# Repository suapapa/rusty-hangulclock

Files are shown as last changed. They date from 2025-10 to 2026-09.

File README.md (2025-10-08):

# Rusty HangulClock

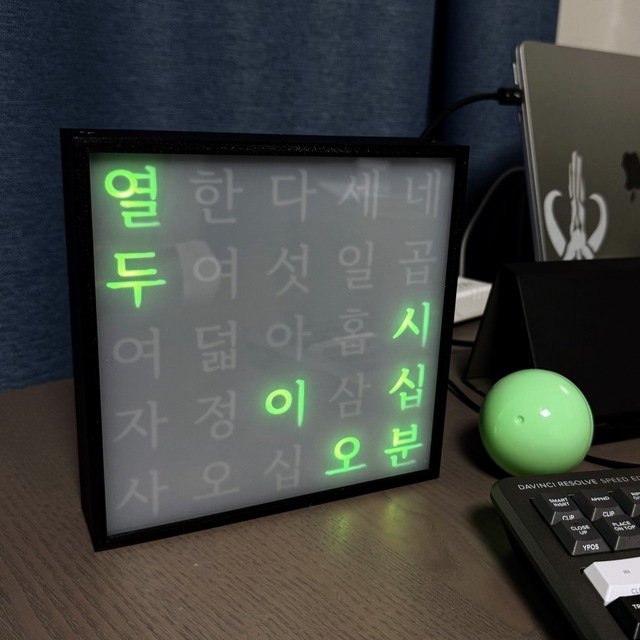
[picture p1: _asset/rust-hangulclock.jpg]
rusty_hangulclock


A HangulClock written in Rust for the ESP32-C3 board.

- [Usage manual](https://hangulclock.homin.dev)
- [Pannel image mager - Web](https://hangulclock.homin.dev/panel-maker)

## Hardware

- [Schematic & PCB artwork](./sch/rusty-hangulclock/) - KiCad project files
- [3D case models](./case/)

## Build and Flash

### Install Toolchain (One-time setup)

```sh
cargo install espup cargo-espflash ldproxy
espup install
```

### Build and Flash

```sh
make flash
```

### Factory Reset

Reset all settings to defaults:

```sh
make erase_nvs
```

## Pre-commit Workflow

Before committing code, run:

```sh
make pre-commit
```

This will run all static analysis tools and ensure your code meets quality standards.

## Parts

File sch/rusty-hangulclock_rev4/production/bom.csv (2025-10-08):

Designator | Footprint | Quantity | Value | LCSC Part #
C1, C10, C11, C12, C13, C14, C15, C17, C18, C19, C2, C20, C21, C22, C23, C24, C25, C26, C27, C28, C3, C30, C31, C34, C4, C6, C7, C8, C9 | C_0402 | 29 | 100nF | C1525
C16, C32, C5 | C_0805 | 3 | 10uF | C15850
C29 | C_0402 | 1 | 22pF | C1555
C35 | C_0402 | 1 | 1uF | C52923
D1 | 0603 | 1 | Red | C2286
D10, D11, D12, D13, D14, D15, D16, D17, D18, D19, D2, D20, D21, D22, D23, D24, D25, D26, D3, D4, D5, D6, D7, D8, D9 | LED_WS2812B_PLCC4_5.0x5.0mm_P3.2mm | 25 | WS2812B | C2874885
D28 | SOT23-6L | 1 | USBLC6-2SC6 | C7519
FB1 | FB_0805 | 1 | ~ | C1015
J4 | USB-TYPE-C-015 | 1 | USB_C_Receptacle_PowerOnly_6P | C2927035
L1 | L_Bourns-SRN4018 | 1 | SPH4018H2R2MT (2.2uH 2.2A) | C370436
Q1, Q2 | Q_SOT-23 | 2 | S8050 | C364312
R1, R5, R8 | R_0402 | 3 | 1kΩ | C11702
R10, R11, R7 | R_0402 | 3 | 10kΩ | C25744
R2, R6 | R_0402 | 2 | 5.1kΩ | C25905
R3 | R_0402 | 1 | 100kΩ | C25741
R4 | R_0402 | 1 | 22kΩ | C25768
U1 | ESP32-C3-WROOM-02 | 1 | ESP32-C3-WROOM-02
U2 | SOT-23-5 | 1 | SY8088 | C479072

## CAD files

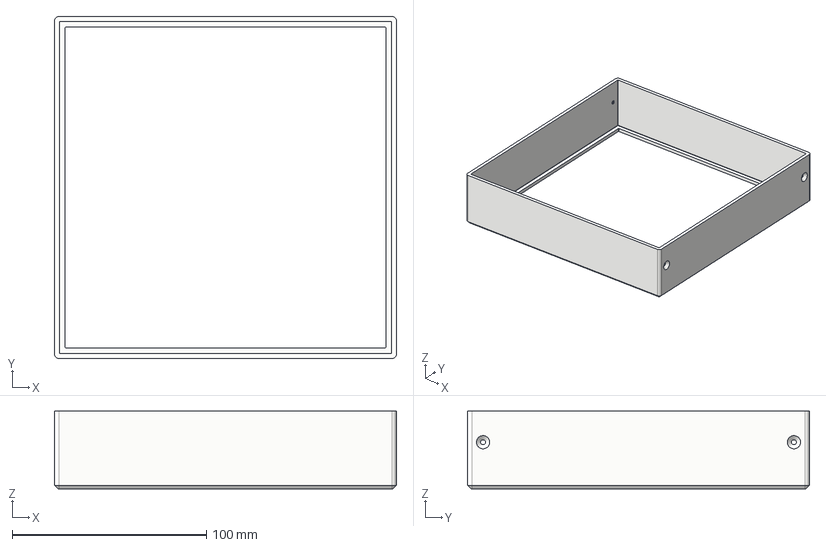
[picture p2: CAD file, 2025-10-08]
case/exp/외부케이스 176x176.step
176.0 x 176.0 x 40.0 mm

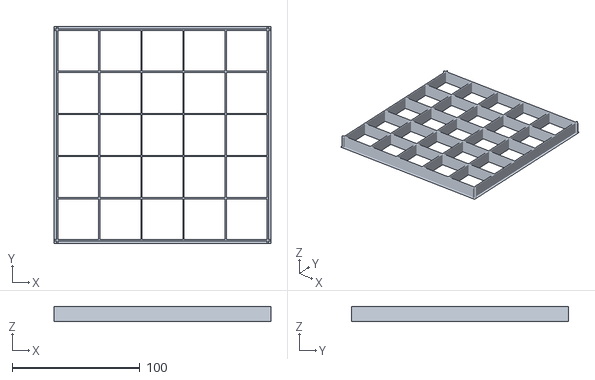
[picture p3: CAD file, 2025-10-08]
case/light_tunnel.stl
170.0 x 170.0 x 12.0

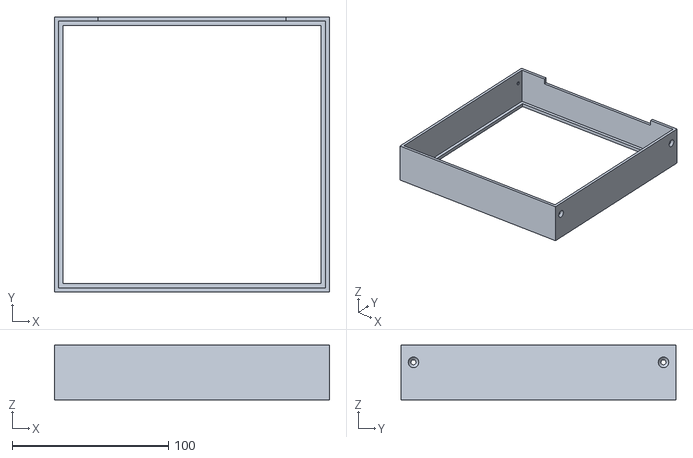
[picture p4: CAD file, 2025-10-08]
case/case.stl
176.0 x 176.0 x 35.0

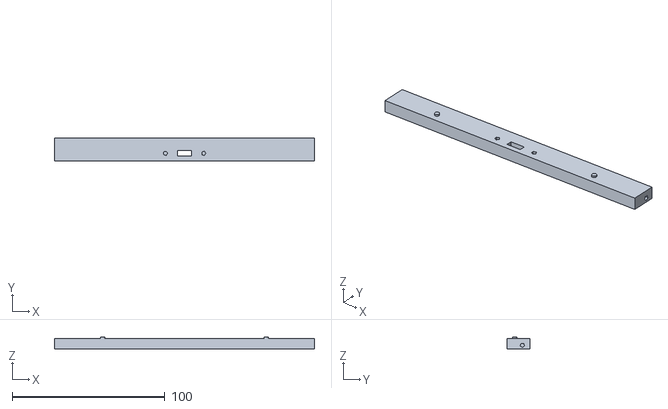
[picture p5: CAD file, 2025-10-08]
case/bridge_bottom.stl
170.0 x 15.0 x 8.00

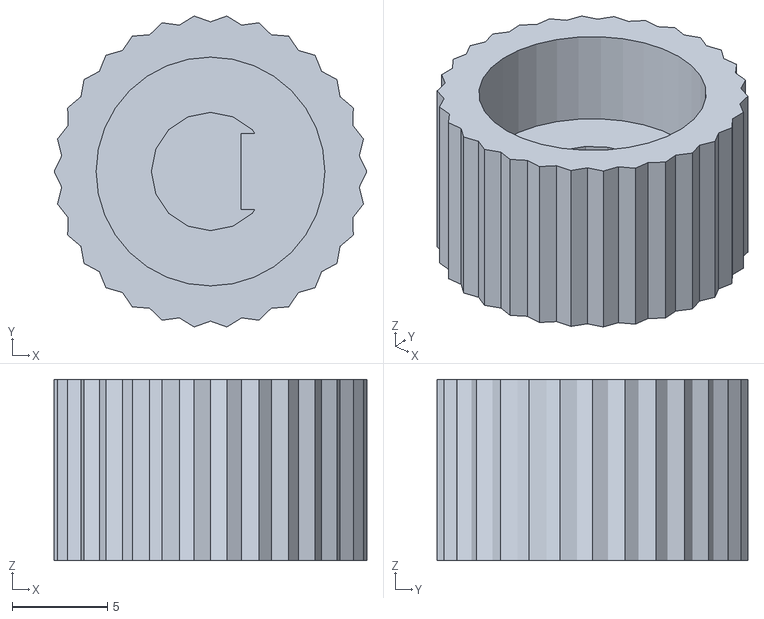
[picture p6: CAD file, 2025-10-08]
case/knob.stl
16.4 x 16.3 x 9.50

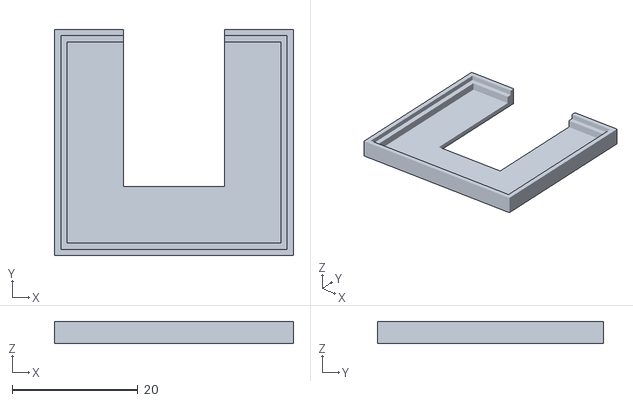
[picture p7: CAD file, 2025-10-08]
case/oled_guide.stl
38.0 x 36.0 x 3.50

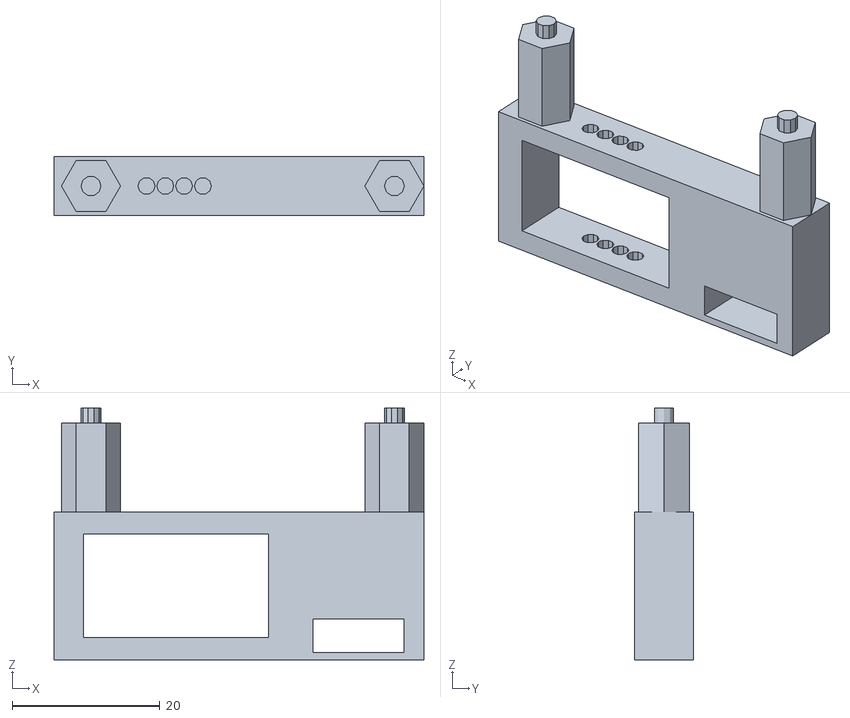
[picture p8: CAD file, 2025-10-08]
case/download_zig.stl
50.0 x 8.00 x 34.0

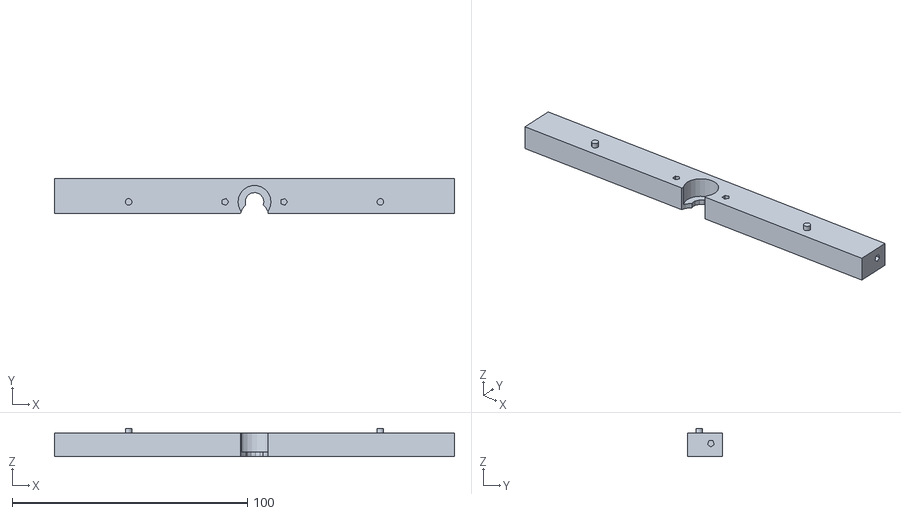
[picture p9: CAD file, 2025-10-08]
case/bridge_top.stl
170.0 x 15.0 x 12.0

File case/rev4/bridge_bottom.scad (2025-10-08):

bar();

module bar(){
    translate([0,0,0])
union(){
    difference() {
        translate([0,2.5,1.5]) cube ([170, 15, 7], center=true);
        #translate([12.5, 0, 4]) cylinder(10, 1.5, 1.5, center=true);
        #translate([-12.5, 0, 4]) cylinder(10, 1.5, 1.5, center=true);
        
        // usb hole
        # cube([9,3.5,10+1], center=true);
        
        // sideholes
        translate([170/2,5,0.6]) rotate([0,90,0]) cylinder(20, 1.5, 1.5, center=true);
        translate([-170/2,5,0.6]) rotate([0,90,0]) cylinder(20, 1.5, 1.5, center=true);
    }
    translate([53.5, 0, 2]) cylinder(8, 1.4, 1.4, center=true, $fn=20);
    translate([-53.5, 0, 2]) cylinder(8, 1.4, 1.4, center=true, $fn=20);
}
}

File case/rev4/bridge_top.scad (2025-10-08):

union(){
    difference() {
        translate([0,2.5,0]) cube ([170, 15 , 10], center=true);
        translate([12.5, 0, 3]) cylinder(10, 1.5, 1.5, center=true);
        translate([-12.5, 0, 3]) cylinder(10, 1.5, 1.5, center=true);
        
        // wall nail hole
        translate([0,0,0]) cylinder(11, 4, 4, center=true);
        translate([0,-6,0]) cylinder(11, 6, 6, center=true);
        translate([0,0,2]) cylinder(10, 7, 7, center=true);
        
        // sideholes
        translate([170/2,5,0.6]) rotate([0,90.0]) cylinder(20, 1.5, 1.5, center=true);
        translate([-170/2,5,0.6]) rotate([0,90.0]) cylinder(20, 1.5, 1.5, center=true);
    }
    translate([53.5, 0, 2]) cylinder(10, 1.4, 1.4, center=true, $fn=20);
    translate([-53.5, 0, 2]) cylinder(10, 1.4, 1.4, center=true, $fn=20);
}

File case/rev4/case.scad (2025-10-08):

difference() {
    translate([0,0,40/2])
        difference() {
            cube([176,176,40-5], center=true);
            cube([165,165,70], center=true);
            translate([0,0,3+2.5]) cube([171,171,40], center=true);
            //translate([2.5,2.5,2.5]) cube([170,170,70]);
            translate([0,50,0+25+5]) cube([120,180,35], center=true);
        }

    translate([-170/2,170/2-5,24+2.5])
        rotate([0,90,0]) screw_hole();
    translate([-170/2,-170/2+5,24+2.5])
        rotate([0,90,0]) screw_hole();
    translate([170/2,170/2-5,24+2.5])
        rotate([0,-90,0]) screw_hole();
    translate([170/2,-170/2+5,24+2.5])
        rotate([0,-90,0]) screw_hole();
}



module screw_hole() {
    translate([0,0,-3])
    union() {
        translate([0,0,5]) cylinder(10, 1.5+0.1, 1.5+0.1, center=true, $fn=20);
        translate([0,0,2.5/2-0.2]) cylinder(2.5+0.1,3.5+0.1,1.5, center=true, $fn=20);
    }
}

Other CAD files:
case/rev4/download_zig.scad
case/exp/외부케이스 176x176.stl
case/rev3/case.scad
case/rev3/case_back.scad
case/rev3/light_pannel.scad
case/rev4/knob.scad
case/rev4/light_tunnel.scad
case/rev4/oled_guide.scad

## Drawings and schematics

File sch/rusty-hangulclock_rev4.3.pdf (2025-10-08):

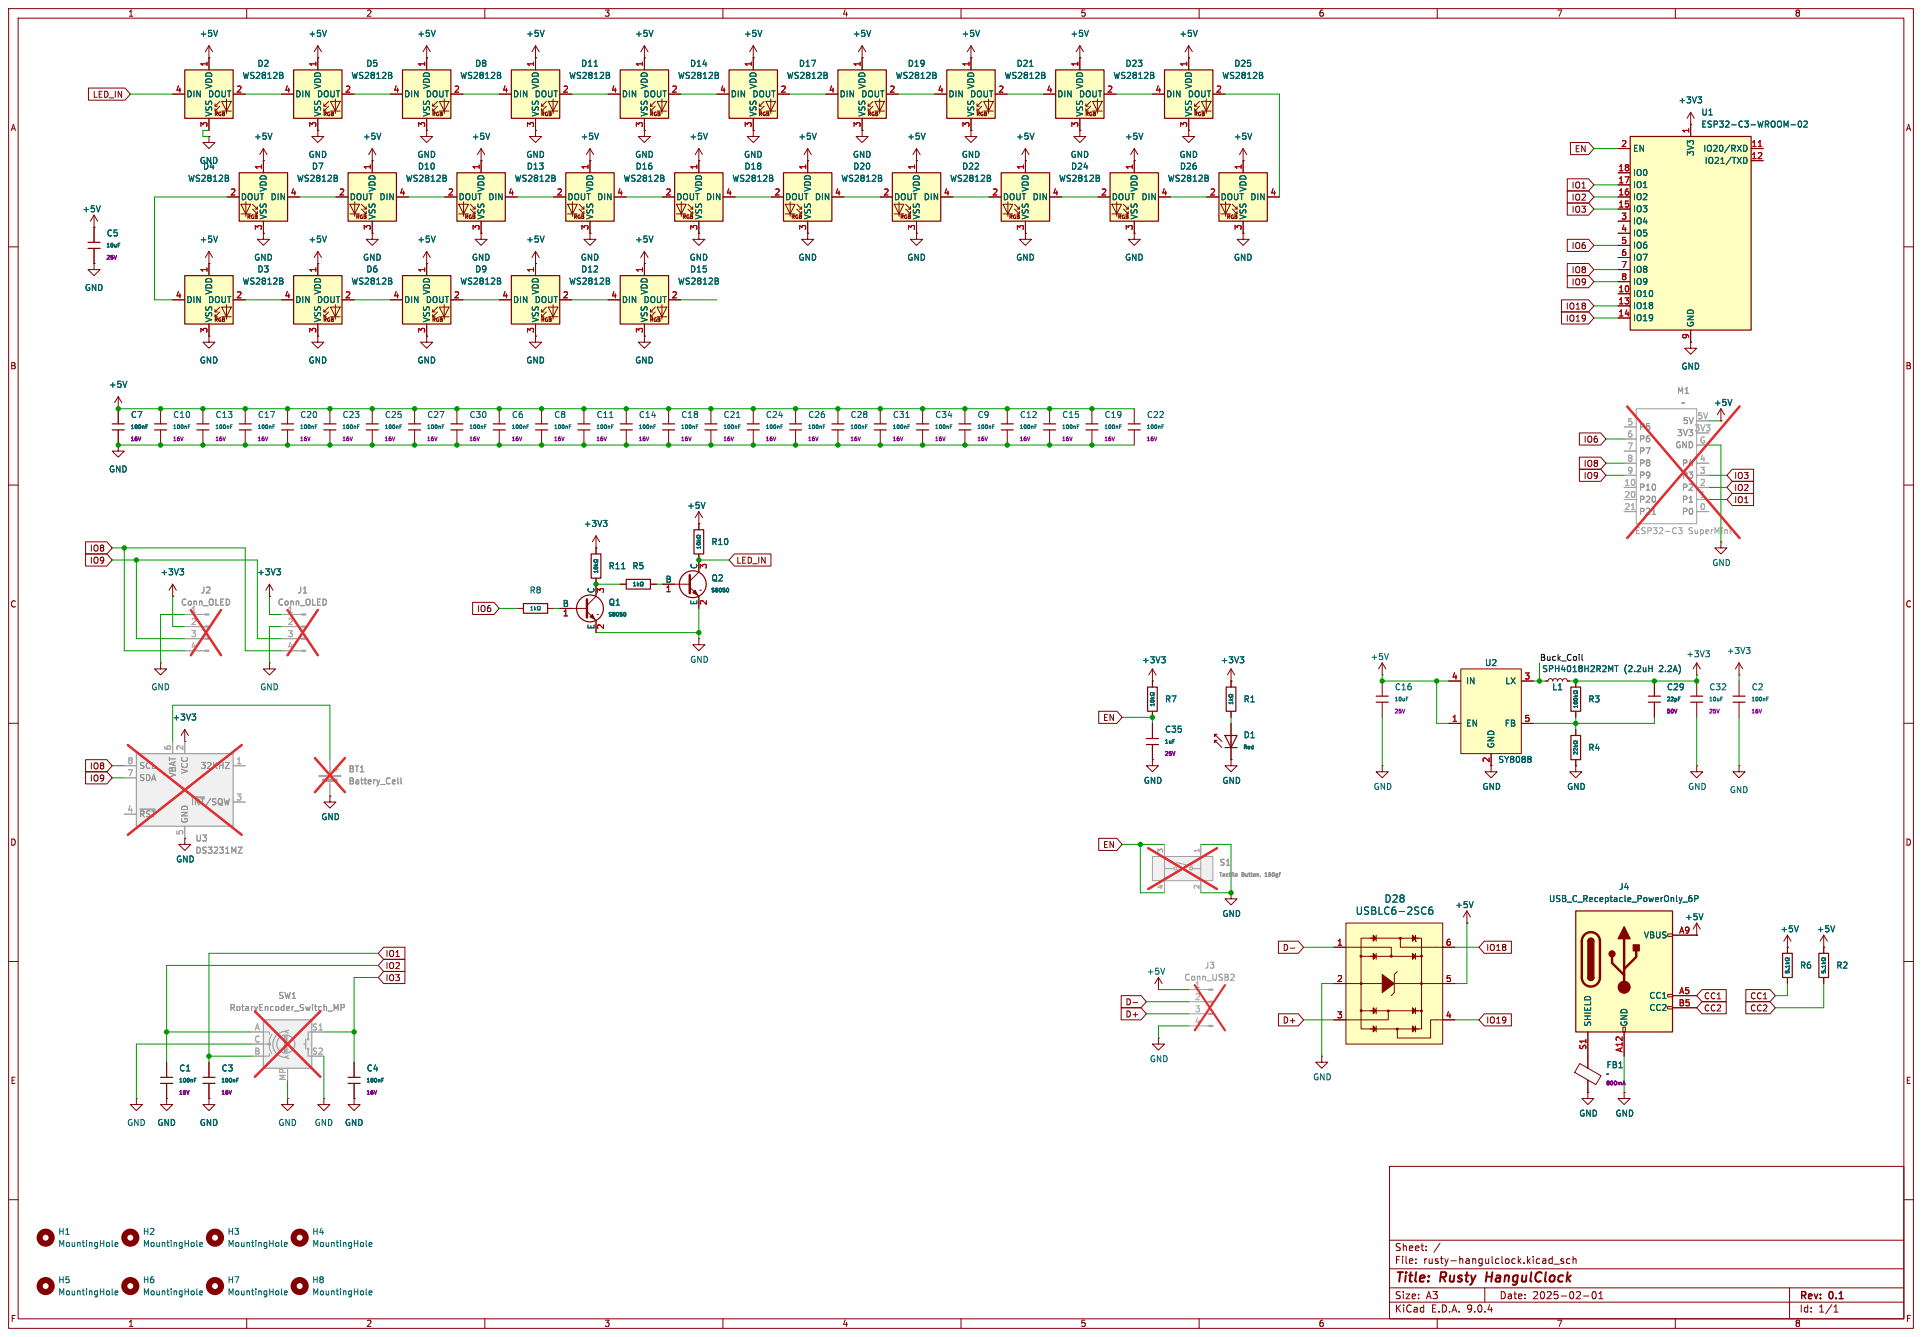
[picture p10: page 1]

3 DOUT 2 D18 WS2812B GND GND GND

File: rusty-hangulclock.kicad_sch Sheet: /
Id: 1/1 Title: Rusty HangulClock

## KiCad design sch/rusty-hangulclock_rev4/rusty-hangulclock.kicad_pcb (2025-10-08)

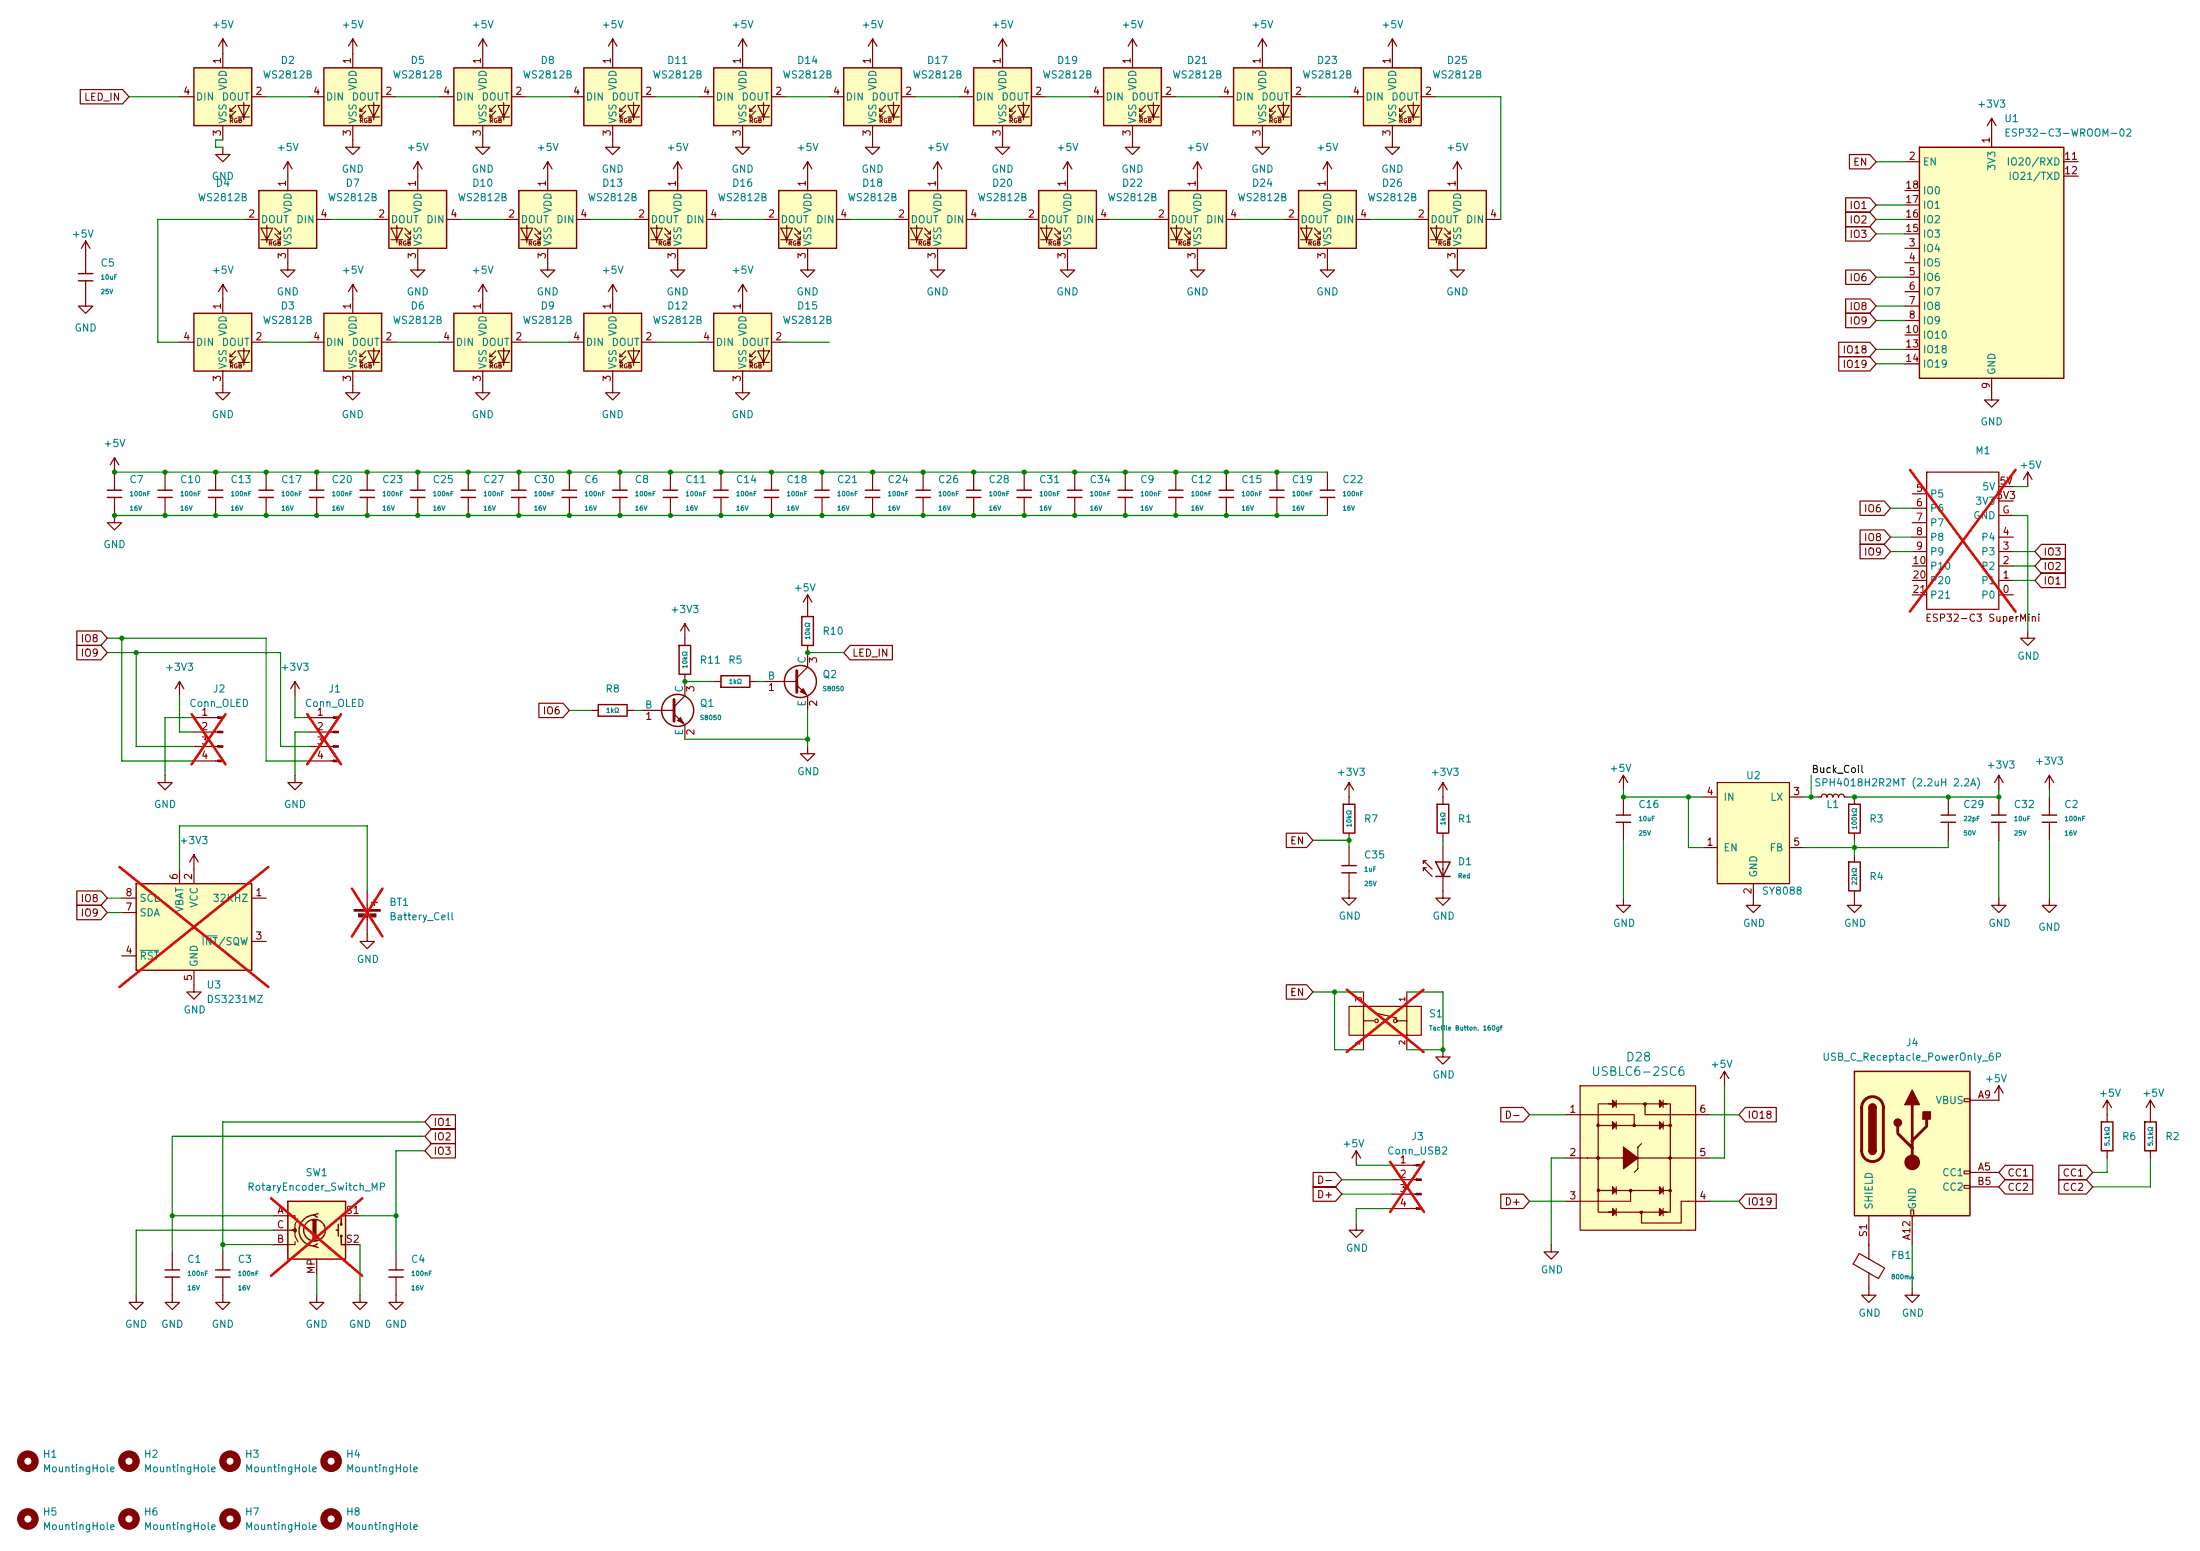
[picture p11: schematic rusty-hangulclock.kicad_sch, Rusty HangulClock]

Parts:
BT1: Battery_Cell; BatteryHolder_Keystone_1060_1x2032; LCSC C70377; not fitted
C1, C2, C3, C4, C6, C7, C8, C9, C10, C11, C12, C13, C14, C15, C17, C18, C19, C20, C21, C22, C23, C24, C25, C26, C27, C28, C30, C31, C34: 100nF; C_0402; Voltage Rated 16V; Tolerance ±10%; Part CL05B104KO5NNNC; LCSC C1525
C5, C16, C32: 10uF; C_0805; Voltage Rated 25V; Tolerance ±10%; Part CL21A106KAYNNNE; LCSC C15850
C29: 22pF; C_0402; Voltage Rated 50V; Tolerance ±5%; Part 0402CG220J500NT; LCSC C1555
C35: 1uF; C_0402; Voltage Rated 25V; Tolerance ±10%; Part CL05A105KA5NQNC; LCSC C52923
D1: Red; LED_0603_1608Metric; Part KT-0603R; LCSC C2286
D2, D3, D4, D5, D6, D7, D8, D9, D10, D11, D12, D13, D14, D15, D16, D17, D18, D19, D20, D21, D22, D23, D24, D25, D26: WS2812B; LED_WS2812B_PLCC4_5.0x5.0mm_P3.2mm; LCSC C2874885
D28: USBLC6-2SC6; SOT23-6L; MPN USBLC6-2SC6; Digi-Key_PN 497-5235-1-ND
FB1: FB_0805; Current Rating 800mA; Tolerance ±25%; Part GZ2012D101TF; LCSC C1015
H1, H2, H3, H4, H5, H6, H7, H8: MountingHole; MountingHole_3.2mm_M3
J1, J2: Conn_OLED; PinHeader_1x04_P2.54mm_Vertical; not fitted
J3: Conn_USB2; PinHeader_1x04_P2.54mm_Vertical; not fitted
J4: USB_C_Receptacle_PowerOnly_6P; USB-TYPE-C-015; LCSC C2927035
L1: SPH4018H2R2MT (2.2uH 2.2A); L_Bourns-SRN4018; LCSC C370436
M1: ESP32-C3_SuperMini_THT; not fitted
Q1, Q2: S8050; Q_SOT-23; Part S8050; LCSC C364312
R1, R5, R8: 1kΩ; R_0402; Overload Voltage (Max) 50V; Tolerance ±1%; Part 0402WGF1001TCE; LCSC C11702
R2, R6: 5.1kΩ; R_0402; Overload Voltage (Max) 50V; Tolerance ±1%; Part 0402WGF5101TCE; LCSC C25905
R3: 100kΩ; R_0402; Overload Voltage (Max) 50V; Tolerance ±1%; Part 0402WGF1003TCE; LCSC C25741
R4: 22kΩ; R_0402; Overload Voltage (Max) 50V; Tolerance ±1%; Part 0402WGF2202TCE; LCSC C25768
R7, R10, R11: 10kΩ; R_0402; Overload Voltage (Max) 50V; Tolerance ±1%; Part 0402WGF1002TCE; LCSC C25744
S1: Tactile Button, 160gf; SW-SMD_4P-L5.1-W5.1-P3.70-LS6.5-TL-2; Voltage Rating (Dc) 12V; Part TS-1187A-B-A-B; LCSC C318884; not fitted
SW1: RotaryEncoder_Switch_MP; RotaryEncoder_Alps_EC11E-Switch_Vertical_H20mm; not fitted
U1: ESP32-C3-WROOM-02
U2: SY8088; SOT-23-5; LCSC C479072
U3: DS3231MZ; SOIC-8_3.9x4.9mm_P1.27mm; LCSC C107410; not fitted

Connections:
+3V3: C2.1, C29.1, C32.1, J1.1, J2.2, L1.2, R1.1, R3.1, R7.1, R11.1, U1.1 (3V3), U3.2 (VCC)
+5V: C5.1, C6.1, C7.1, C8.1, C9.1, C10.1, C11.1, C12.1, C13.1, C14.1, C15.1, C16.1, C17.1, C18.1, C19.1, C20.1, C21.1, C22.1, C23.1, C24.1, C25.1, C26.1, C27.1, C28.1, C30.1, C31.1, C34.1, D2.1 (VDD), D3.1 (VDD), D4.1 (VDD), D5.1 (VDD), D6.1 (VDD), D7.1 (VDD), D8.1 (VDD), D9.1 (VDD), D10.1 (VDD), D11.1 (VDD), D12.1 (VDD), D13.1 (VDD), D14.1 (VDD), D15.1 (VDD), D16.1 (VDD), D17.1 (VDD), D18.1 (VDD), D19.1 (VDD), D20.1 (VDD), D21.1 (VDD), D22.1 (VDD), D23.1 (VDD), D24.1 (VDD), D25.1 (VDD), D26.1 (VDD), D28.5, J3.1, J4.A9 (VBUS), J4.B9 (VBUS), M1.5V, R2.1, R6.1, R10.1, U2.1 (EN), U2.4 (IN)
/Buck_Coil: L1.1, U2.3 (LX)
CC1: J4.A5 (CC1), R6.2
CC2: J4.B5 (CC2), R2.2
D+: D28.3, J3.3
D-: D28.1, J3.2
EN: C35.1, R7.2, S1.3 (C), S1.4 (D), U1.2 (EN)
GND: BT1.2 (-), C1.2, C2.2, C3.2, C4.2, C5.2, C6.2, C7.2, C8.2, C9.2, C10.2, C11.2, C12.2, C13.2, C14.2, C15.2, C16.2, C17.2, C18.2, C19.2, C20.2, C21.2, C22.2, C23.2, C24.2, C25.2, C26.2, C27.2, C28.2, C30.2, C31.2, C32.2, C34.2, C35.2, D1.1, D2.3 (VSS), D3.3 (VSS), D4.3 (VSS), D5.3 (VSS), D6.3 (VSS), D7.3 (VSS), D8.3 (VSS), D9.3 (VSS), D10.3 (VSS), D11.3 (VSS), D12.3 (VSS), D13.3 (VSS), D14.3 (VSS), D15.3 (VSS), D16.3 (VSS), D17.3 (VSS), D18.3 (VSS), D19.3 (VSS), D20.3 (VSS), D21.3 (VSS), D22.3 (VSS), D23.3 (VSS), D24.3 (VSS), D25.3 (VSS), D26.3 (VSS), D28.2, FB1.2, J1.2, J2.1, J3.4, J4.A12 (GND), J4.B12 (GND), M1.G (GND), Q1.2 (E), Q2.2 (E), R4.2, S1.1 (A), S1.2 (B), SW1.C, SW1.MP, SW1.S2, U1.9 (GND), U1.19 (GND), U2.2 (GND), U3.5 (GND)
IO1: C3.1, M1.1, SW1.B, U1.17 (IO1)
IO2: C1.1, M1.2, SW1.A, U1.16 (IO2)
IO3: C4.1, M1.3, SW1.S1, U1.15 (IO3)
IO6: M1.6, R8.1, U1.5 (IO6)
IO8: J1.4, J2.4, M1.8, U1.7 (IO8), U3.8 (SCL)
IO9: J1.3, J2.3, M1.9, U1.8 (IO9), U3.7 (SDA)
IO18: D28.6, U1.13 (IO18)
IO19: D28.4, U1.14 (IO19)
LED_IN: D2.4 (DIN), Q2.3 (C), R10.2
unnamed: BT1.1 (+), U3.6 (VBAT)
unnamed: D1.2, R1.2
unnamed: D2.2 (DOUT), D5.4 (DIN)
unnamed: D3.4 (DIN), D4.2 (DOUT)
unnamed: D3.2 (DOUT), D6.4 (DIN)
unnamed: D4.4 (DIN), D7.2 (DOUT)
unnamed: D5.2 (DOUT), D8.4 (DIN)
unnamed: D6.2 (DOUT), D9.4 (DIN)
unnamed: D10.4 (DIN), D13.2 (DOUT)
unnamed: D7.4 (DIN), D10.2 (DOUT)
unnamed: D8.2 (DOUT), D11.4 (DIN)
unnamed: D11.2 (DOUT), D14.4 (DIN)
unnamed: D9.2 (DOUT), D12.4 (DIN)
unnamed: D12.2 (DOUT), D15.4 (DIN)
unnamed: D13.4 (DIN), D16.2 (DOUT)
unnamed: D14.2 (DOUT), D17.4 (DIN)
unnamed: D16.4 (DIN), D18.2 (DOUT)
unnamed: D17.2 (DOUT), D19.4 (DIN)
unnamed: D18.4 (DIN), D20.2 (DOUT)
unnamed: D19.2 (DOUT), D21.4 (DIN)
unnamed: D20.4 (DIN), D22.2 (DOUT)
unnamed: D21.2 (DOUT), D23.4 (DIN)
unnamed: D22.4 (DIN), D24.2 (DOUT)
unnamed: D23.2 (DOUT), D25.4 (DIN)
unnamed: D24.4 (DIN), D26.2 (DOUT)
unnamed: D25.2 (DOUT), D26.4 (DIN)
unnamed: FB1.1, J4.S1 (SHIELD)
unnamed: Q1.1 (B), R8.2
unnamed: Q1.3 (C), R5.1, R11.2
unnamed: Q2.1 (B), R5.2
unnamed: C29.2, R3.2, R4.1, U2.5 (FB)

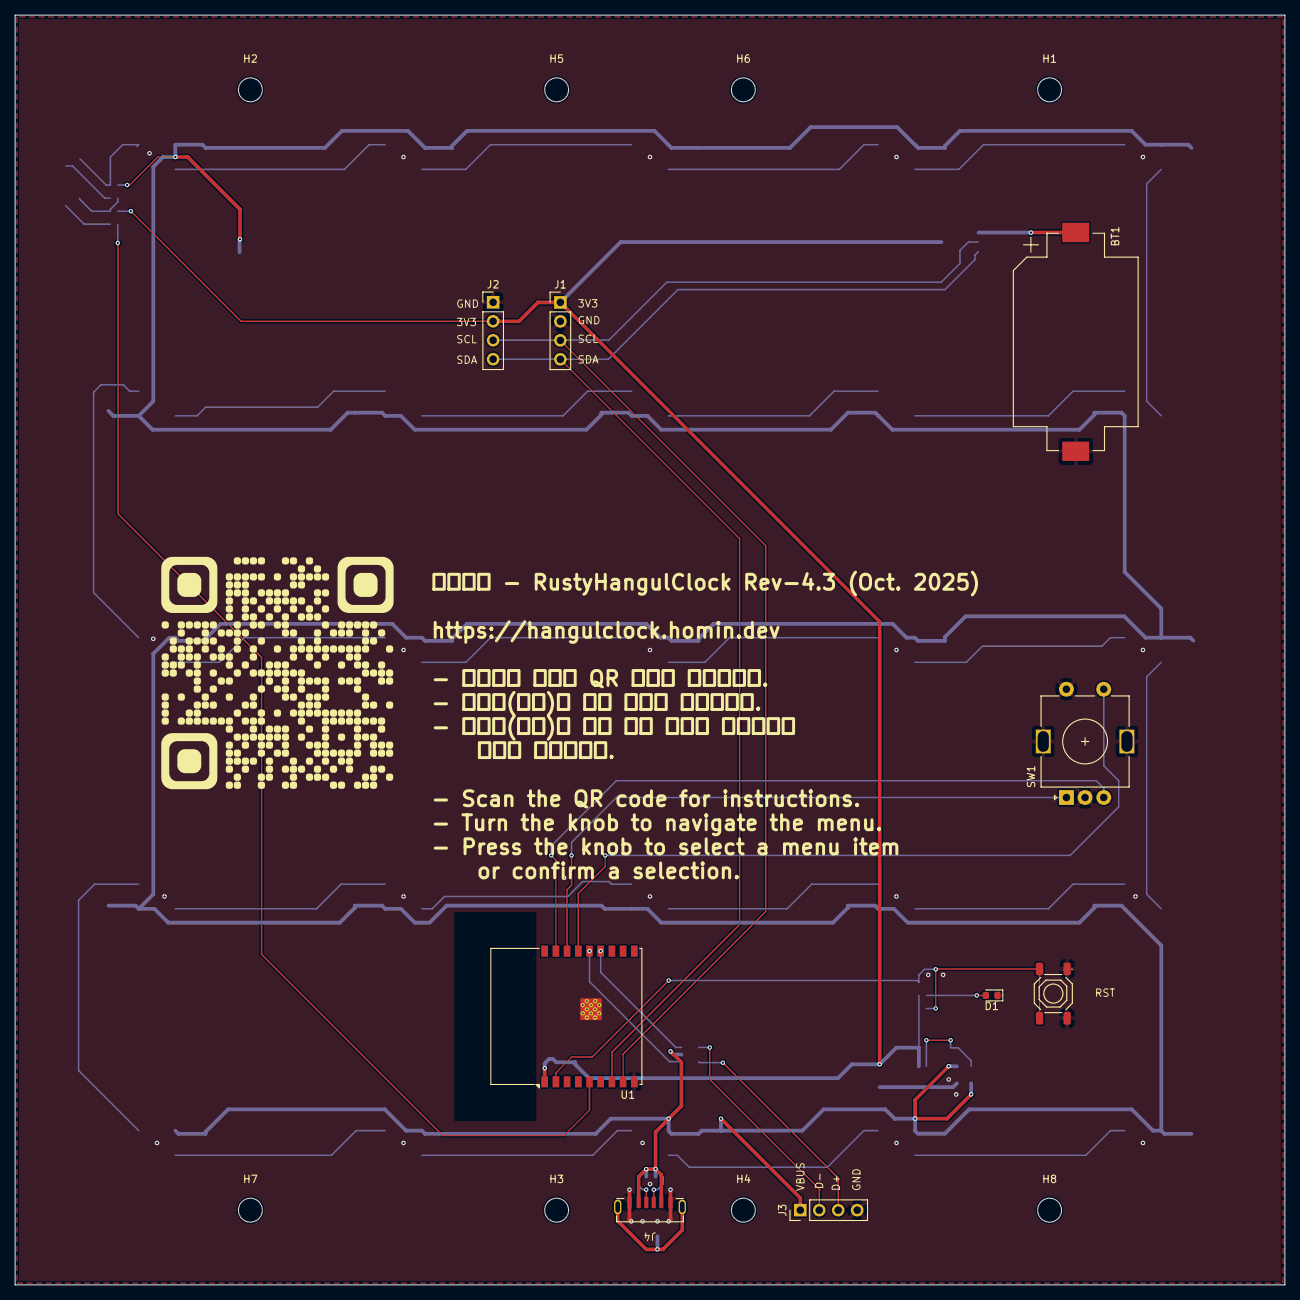
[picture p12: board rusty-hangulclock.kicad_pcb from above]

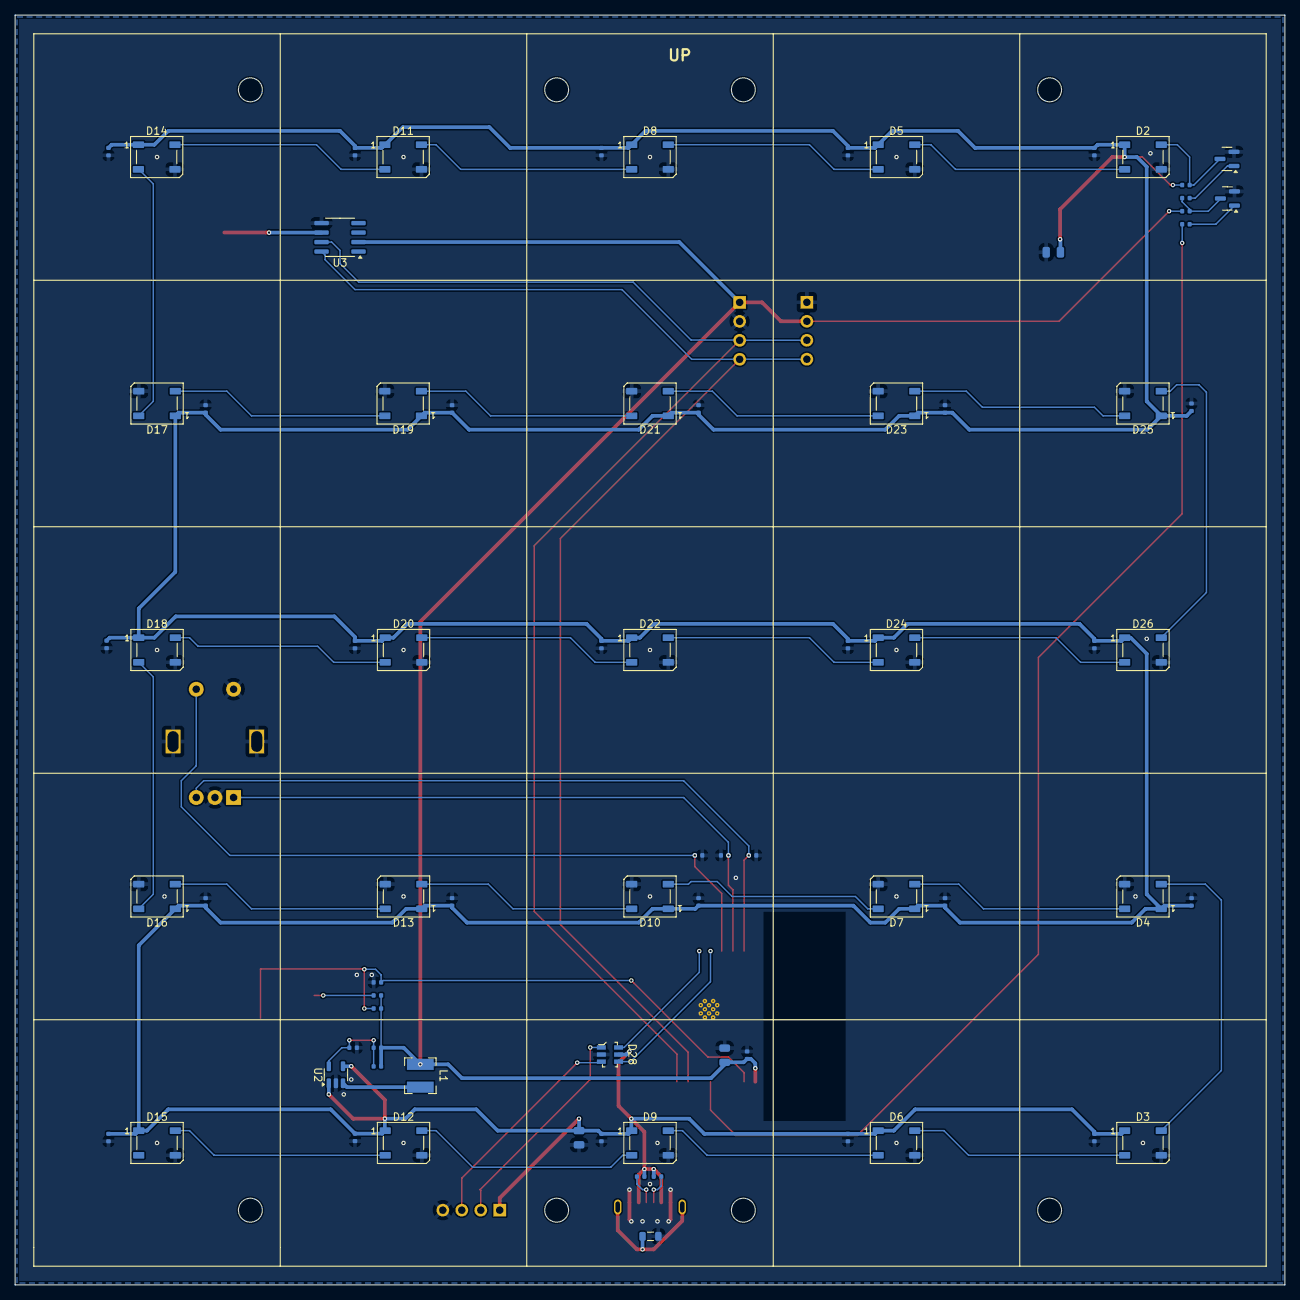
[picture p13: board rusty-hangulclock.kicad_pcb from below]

Board: 2 copper layers, 170.0 x 170.0 mm, 93 parts (76 on the bottom side), 49 nets.

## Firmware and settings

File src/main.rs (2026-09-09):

mod global;
mod menu;
mod net;
mod nvs;
mod ota_update;
mod panel;
mod report;
mod rotary;
mod timer;
mod web_server;

use chrono::prelude::*;
use esp_idf_svc::eventloop::EspSystemEventLoop;
use esp_idf_svc::hal::gpio::*;
use esp_idf_svc::hal::i2c::*;
use esp_idf_svc::hal::peripherals::Peripherals;
use esp_idf_svc::hal::reset::restart;
use esp_idf_svc::hal::spi::config::{Config as SpiConfig, DriverConfig as SpiDriverConfig};
use esp_idf_svc::hal::spi::{SpiBusDriver, SpiDriver};
use esp_idf_svc::hal::units::*;
use esp_idf_svc::nvs::EspDefaultNvsPartition;
use esp_idf_svc::timer::EspTaskTimerService;
use esp_idf_svc::wifi::{AsyncWifi, EspWifi};
use log::{debug, info, warn};
use sh1106::prelude::GraphicsMode as Sh1106GM;
use sh1106::Builder as Sh1106Builder;
use ws2812_spi::MODE as SPI_MODE;

fn main() -> anyhow::Result<()> {
    esp_idf_svc::sys::link_patches();
    esp_idf_svc::log::EspLogger::initialize_default();

    setup_panic_hook();
    info!("Hello, RustyHangulClock!");

    let p = Peripherals::take()?;
    let menu_sel = PinDriver::input(p.pins.gpio3, Pull::Up)?;
    let menu_r1 = PinDriver::input(p.pins.gpio2, Pull::Up)?;
    let menu_r2 = PinDriver::input(p.pins.gpio1, Pull::Up)?;

    // OLED initialization
    let i2c_config = I2cConfig::new().baudrate(50_u32.kHz().into());
    let i2c = I2cDriver::new(p.i2c0, p.pins.gpio8, p.pins.gpio9, &i2c_config)?;
    let mut disp: Sh1106GM<_> = Sh1106Builder::new().connect_i2c(i2c).into();
    disp.init()
        .map_err(|e| anyhow::anyhow!("OLED init failed: {:?}", e))?;

    let hw_rev = global::get_hw_revision();
    let rotation = if hw_rev == 4 {
        sh1106::prelude::DisplayRotation::Rotate270
    } else {
        sh1106::prelude::DisplayRotation::Rotate90
    };
    disp.set_rotation(rotation).ok();
    disp.flush().ok();

    menu::draw_text(
        &mut disp,
        &format!(
            "Rusty\nHangul\nClock\nrev.{}\n\nno.{}\nver.{}\n\ninit...",
            hw_rev,
            nvs::get_device_no()?,
            global::get_sw_version()
        ),
    )?;

    // SPI & LEDs initialization
    let mut spi_driver = SpiDriver::new(
        p.spi2,
        p.pins.gpio4,
        p.pins.gpio6,
        AnyIOPin::none(),
        &SpiDriverConfig::new(),
    )?;
    let spi_config = SpiConfig::new()
        .baudrate(3200_u32.kHz().into())
        .data_mode(SPI_MODE);
    let spi_bus = SpiBusDriver::new(&mut spi_driver, &spi_config)?;
    let mut sleds = panel::Sleds::new(spi_bus);

    let sys_loop = EspSystemEventLoop::take()?;
    let timer_service = EspTaskTimerService::new()?;
    let nvs_partition = EspDefaultNvsPartition::take()?;
    let mut wifi = AsyncWifi::wrap(
        EspWifi::new(p.modem, sys_loop.clone(), Some(nvs_partition))?,
        sys_loop,
        timer_service,
    )?;

    futures::executor::block_on(async {
        inc_boot_count().await?;
        sleds.welcome().await;

        info!("Starting tasks...");
        global::register_task_with_wdt("main");
        global::start_stall_watchdog();

        let net_task = net::net_loop(&mut wifi);
        let show_time_task = show_time_loop(&mut sleds);
        let menu_task = menu::menu_loop(&mut disp, menu_sel);
        let time_sync_task = time_sync_loop();
        let rotary_encoder_task = rotary::rotary_encoder_loop(menu_r2, menu_r1);

        match futures::try_join!(
            menu_task,
            net_task,
            time_sync_task,
            show_time_task,
            rotary_encoder_task
        ) {
            Ok(_) => info!("All tasks completed"),
            Err(e) => warn!("Task error: {:?}", e),
        }
        Ok::<(), anyhow::Error>(())
    })?;

    info!("Restarting...");
    restart();

    // Ok(())
}

fn setup_panic_hook() {
    std::panic::set_hook(Box::new(|panic_info| {
        log::error!("Panic: {:?}", panic_info);

        let in_special_mode = *global::AP_MODE.lock().unwrap() || *global::OTA_MODE.lock().unwrap();
        if in_special_mode {
            warn!("Skipping restart in AP/OTA mode");
        } else {
            warn!("Restarting in 3 seconds...");
            restart();
        }
    }));
}

async fn time_sync_loop() -> anyhow::Result<()> {
    let mut watchdog = global::WatchdogManager::new(global::TaskId::TimeSync, 60, 10);
    let mut sync_check_cnt: u64 = 0;

    loop {
        timer::sleep_secs(60).await;
        if watchdog.update() {
            global::yield_to_other_tasks().await;
        }
        if net::check_net_cmd_or_skip().await.is_err() {
            continue;
        }

        // Sync every 3 days
        sync_check_cnt = (sync_check_cnt + 1) % (60 * 24 * 3);
        if sync_check_cnt == 0 {
            info!("Starting periodic time sync");
            if net::set_net_cmd("NTP") {
                let start = std::time::Instant::now();
                while start.elapsed().as_secs() < 60 {
                    global::heartbeat(global::TaskId::TimeSync);
                    let res = net::get_result_net();
                    if res == "OK" || res == "NG" {
                        break;
                    }
                    timer::sleep_secs(5).await;
                }
                net::set_result_net("");
            }
        }
    }
}

async fn inc_boot_count() -> anyhow::Result<()> {
    let count = nvs::get_boot_count()?.saturating_add(1);
    nvs::set_boot_count(count)
}

async fn show_time_loop<SPI: embedded_hal::spi::SpiBus>(
    sleds: &mut panel::Sleds<SPI>,
) -> anyhow::Result<()> {
    let mut watchdog = global::WatchdogManager::new(global::TaskId::ShowTime, 60, 10);
    let mut last_h = 255;
    let mut last_m = 255;
    let utc_offset = i64::from(nvs::get_utc_offset().unwrap_or(9));

    loop {
        if watchdog.update() {
            global::yield_to_other_tasks().await;
        }
        if net::check_net_cmd_or_skip().await.is_err() {
            timer::sleep_secs(1).await;
            continue;
        }

        let skip_display =
            *global::IN_MENU.lock().unwrap() || !*global::TIME_SYNCED.lock().unwrap();
        if skip_display {
            sleds.turn_on_all().await;
            last_h = 255;
            last_m = 255;
            timer::sleep_secs(1).await;
            continue;
        }

        let now = chrono::Utc::now() + chrono::Duration::hours(utc_offset);
        let h = now.hour() as u8;
        let m = now.minute() as u8;

        if h != last_h || m != last_m {
            last_h = h;
            last_m = m;
            {
                if let Ok(mut gh) = global::CUR_H.try_lock() {
                    *gh = h;
                }
                if let Ok(mut gm) = global::CUR_M.try_lock() {
                    *gm = m;
                }
            }
            debug!("Updating time: {:02}:{:02}", h, m);
            sleds.show_time(h, m).await;
        }
        timer::sleep_secs(1).await;
    }
}

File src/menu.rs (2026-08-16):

use std::time;

use esp_idf_svc::hal::i2c::*;
use esp_idf_svc::hal::reset::restart;
use log::info;
use sh1106::prelude::{GraphicsMode as Sh1106GM, I2cInterface};

use crate::{global, net, nvs, timer};

#[derive(Debug, Clone, Copy, PartialEq, Eq)]
enum MenuOption {
    Ota,
    LedHue,
    LedSat,
    LedVal,
    UtcOffset,
    ApMode,
    Wps,
    Ntp,
    Exit,
}

impl MenuOption {
    fn as_str(&self) -> &'static str {
        match self {
            MenuOption::Ota => "OTA",
            MenuOption::LedHue => "LED HUE",
            MenuOption::LedSat => "LED SAT",
            MenuOption::LedVal => "LED VAL",
            MenuOption::UtcOffset => "UTC OFFSET",
            MenuOption::ApMode => "AP MODE",
            MenuOption::Wps => "WPS",
            MenuOption::Ntp => "NTP",
            MenuOption::Exit => "EXIT",
        }
    }

    fn next(&self) -> Self {
        use MenuOption::*;
        match self {
            Ota => LedHue,
            LedHue => LedSat,
            LedSat => LedVal,
            LedVal => UtcOffset,
            UtcOffset => ApMode,
            ApMode => Wps,
            Wps => Ntp,
            Ntp => Exit,
            Exit => Ota,
        }
    }

    fn prev(&self) -> Self {
        use MenuOption::*;
        match self {
            Ota => Exit,
            LedHue => Ota,
            LedSat => LedHue,
            LedVal => LedSat,
            UtcOffset => LedVal,
            ApMode => UtcOffset,
            Wps => ApMode,
            Ntp => Wps,
            Exit => Ntp,
        }
    }

    fn index(&self) -> usize {
        *self as usize
    }

    const ALL: [Self; 9] = [
        Self::Ota,
        Self::LedHue,
        Self::LedSat,
        Self::LedVal,
        Self::UtcOffset,
        Self::ApMode,
        Self::Wps,
        Self::Ntp,
        Self::Exit,
    ];
}

pub async fn menu_loop(
    disp: &mut Sh1106GM<I2cInterface<I2cDriver<'_>>>,
    mut p_sel: impl embedded_hal::digital::InputPin,
) -> anyhow::Result<()> {
    info!("Starting menu_loop()...");

    let mut current_menu = MenuOption::Wps;
    let menu_len = MenuOption::ALL.len();
    let mut menu_enter_ts = get_ts();
    let mut sub_menu = false;
    let mut watchdog = global::WatchdogManager::new(global::TaskId::Menu, 200, 20);

    let owner_str = nvs::get_owner()
        .ok()
        .filter(|o| !o.is_empty())
        .map(|o| format!("\n\nfor\n{}", o))
        .unwrap_or_default();

    loop {
        timer::sleep_millis(50).await;

        if watchdog.update() {
            global::yield_to_other_tasks().await;
        }

        if net::check_net_cmd_or_skip().await.is_err() {
            continue;
        }

        let in_menu = *global::IN_MENU.lock().unwrap();

        if !in_menu {
            let h = *global::CUR_H.lock().unwrap();
            let m = *global::CUR_M.lock().unwrap();
            draw_text(
                disp,
                &format!("Rusty\nHangul\nClock{}\n\n{:02}:{:02}", owner_str, h, m),
            )?;

            if let Ok(mut event) = global::ROTARY_EVENT.try_lock() {
                if *event != global::RotaryEvent::None {
                    *event = global::RotaryEvent::None;
                    info!("Entering menu");
                    *global::IN_MENU.lock().unwrap() = true;
                    current_menu = MenuOption::Ota;
                    sub_menu = false;
                    menu_enter_ts = get_ts();
                }
            }
        } else {
            // Auto exit menu after 60 seconds
            if get_ts().saturating_sub(menu_enter_ts) > 60_000 {
                info!("Menu timeout, exiting");
                *global::IN_MENU.lock().unwrap() = false;
                continue;
            }

            if sub_menu {
                handle_sub_menu(
                    disp,
                    &mut current_menu,
                    &mut sub_menu,
                    &mut menu_enter_ts,
                    &mut p_sel,
                )
                .await?;
            } else {
                handle_main_menu(
                    disp,
                    &mut current_menu,
                    &mut sub_menu,
                    &mut menu_enter_ts,
                    &mut p_sel,
                    menu_len,
                )
                .await?;
            }
        }
    }
}

async fn handle_main_menu(
    disp: &mut Sh1106GM<I2cInterface<I2cDriver<'_>>>,
    current_menu: &mut MenuOption,
    sub_menu: &mut bool,
    menu_enter_ts: &mut u128,
    p_sel: &mut impl embedded_hal::digital::InputPin,
    menu_len: usize,
) -> anyhow::Result<()> {
    draw_text(
        disp,
        &format!(
            "=MENU {}/{}=\n\n{}\n\npress\nto\ndecide",
            current_menu.index() + 1,
            menu_len,
            current_menu.as_str()
        ),
    )?;

    if let Ok(mut event) = global::ROTARY_EVENT.try_lock() {
        match *event {
            global::RotaryEvent::Clockwise => {
                *current_menu = current_menu.next();
                *menu_enter_ts = get_ts();
            }
            global::RotaryEvent::CounterClockwise => {
                *current_menu = current_menu.prev();
                *menu_enter_ts = get_ts();
            }
            _ => {}
        }
        *event = global::RotaryEvent::None;
    }

    if p_sel.is_low().unwrap_or(false) {
        *menu_enter_ts = get_ts();
        match *current_menu {
            MenuOption::Exit => {
                *global::IN_MENU.lock().unwrap() = false;
                timer::sleep_secs(1).await;
            }
            MenuOption::LedHue
            | MenuOption::LedSat
            | MenuOption::LedVal
            | MenuOption::UtcOffset => {
                *sub_menu = true;
                timer::sleep_millis(200).await;
            }
            _ => {
                let cmd = current_menu.as_str();
                if net::set_net_cmd(cmd) {
                    draw_text(
                        disp,
                        &format!(
                            "MENU {}/{}\n\n**{}**\n\nwait...",
                            current_menu.index() + 1,
                            menu_len,
                            cmd
                        ),
                    )?;
                    let _ =
                        wait_for_net_result(disp, current_menu.index(), menu_len, cmd, 60).await;
                }
            }
        }
    }
    Ok(())
}
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

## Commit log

2025-10-08 feat: initial commit of RustyHangulclock (rev. 4)
    [bom.csv, bridge_bottom.scad, bridge_bottom.stl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]
2025-10-29 refactor: clean up rotary encoder loop by removing unused timer and adjusting debounce logic
2025-10-29 fix: don't abot in wdt
    [main.rs]
2025-12-05 feat: skip LED updates when network commands are pending
    [panel.rs]
2026-01-01 refactor: acquire LED sleds lock before interrupt-free block and remove LED write error logging
    [panel.rs]
2026-01-03 feat: Add scripts for flashing and building OTA binaries, and update .gitignore to track them.
2026-02-28 fix: prevent integer overflow for boot count and division by zero in OTA progress calculation.
    [main.rs]
2026-03-21 fix(net): add 30s timeout to wifi connection to prevent freezing
    Previously, wifi.connect() and wait_netif_up() could hang indefinitely if the AP was unreachable. This would leave CMD_NET set, causing show_time_loop to skip updates and freeze the clock.
    [main.rs]
2026-03-26 Refactor and optimize for ESP32C3 environment
    - Replace lazy_static with once_cell::sync::Lazy
    - Improve WatchdogManager and simplify task yielding
    - Async-ify LED panel updates and minimize heap allocations
    - Structure network commands with NetCmd enum
    - Consolidate NVS access with a helper function
    - Refactor main loop to use futures::try_join!
    - Clean up menu, rotary, and OTA update logic
    [main.rs, menu.rs, panel.rs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]
2026-03-26 chore: fix lint warnnings
    [main.rs, menu.rs, panel.rs]
2026-06-20 fix(net): add timeouts to wifi.start() and wifi.stop() to prevent clock freeze
    wifi.start() and wifi.stop() had no timeout, so an occasional ESP-IDF
    WiFi driver hang would leave CMD_NET="NTP" set indefinitely. This caused
    show_time_loop to skip all display updates forever, freezing the clock.
    Added 15s embassy_time::with_timeout() wrappers to all wifi.start() and
    wifi.stop() calls (NTP, WPS, OTA, AP paths). On timeout the error
    propagates through net_loop which calls clear_net_cmd(), unblocking the
    display loop.
2026-08-16 fix: recover from hung tasks with progress-based stall watchdog
    embassy timeouts cannot interrupt blocking ESP-IDF I/O, so a silent
    net/OTA hang could freeze the clock for days. Heartbeat each loop and
    restart from a separate thread, using download progress for OTA instead
    of a wall-clock timeout.
    [main.rs, menu.rs, rotary.rs]
2026-09-09 Add Jenkins pipeline for manual OTA build and CDN deploy.
    Track release helper scripts, parameterize asset paths, and wire the
    shared-lib steps so OTA bins can be built and published from Jenkins.
2026-09-09 Make LED driver dependencies optional
